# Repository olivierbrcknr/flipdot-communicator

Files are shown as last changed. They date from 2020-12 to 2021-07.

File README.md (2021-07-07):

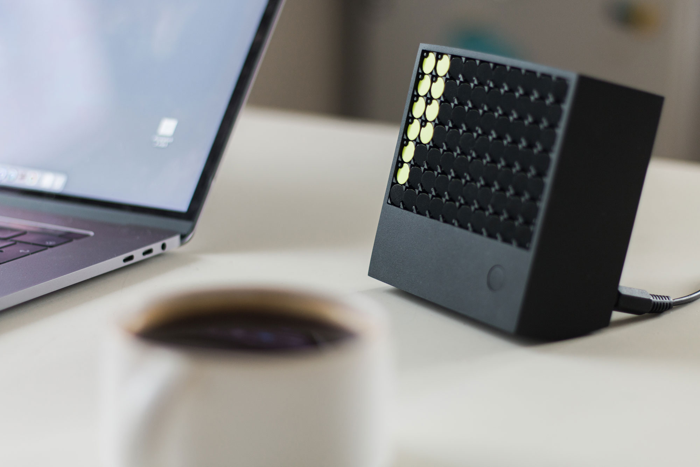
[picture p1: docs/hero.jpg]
FlipDot Communicator


# FlipDot Communicator — Distant Socializing

The *FlipDotCommunicator* is a device for ~~social distancing~~ [distant socializing](https://zirkus-zirkus.com/products/not-alone-bandana).

In these times of high paced, direct digital communication, it is a reminder of the physical and the momentariness. It is a tool to embrace non-explicit communication.

With its soft and erratic flipping sounds, it should bring a little bit of humanness back to our living space. Every message that is received is deleted immediately from the server. When pressing the button, the content is displayed. Once the button is pressed again, the transmission is gone forever. It can stay forever, but thereby it hinders new messages from being received.

It exists in this moment and this moment only—one message at a time. It forces the user to acknowledge the evanescence of a moment, pushing to cherish them more again.

###### Background

This project has been made during the class [Major Studio 1](https://courses.newschool.edu/courses/PGTE5200/1588/) by [Salome Asega](http://www.salome.zone) and [American Artist](https://americanartist.us) in the program [MFA Design & Technology](https://www.newschool.edu/parsons/mfa-design-technology) at Parsons School of Design.

Find the detailed [project blog here](https://olivierbrcknr.github.io/mfadt-ms1-blog/).

## Hardware

This project is built to use [flip-dots](https://github.com/ndsh/flipdots). The little communicator is a hardware piece that receives abstract messages. Here are some examples of how it works:

#### Read A Message
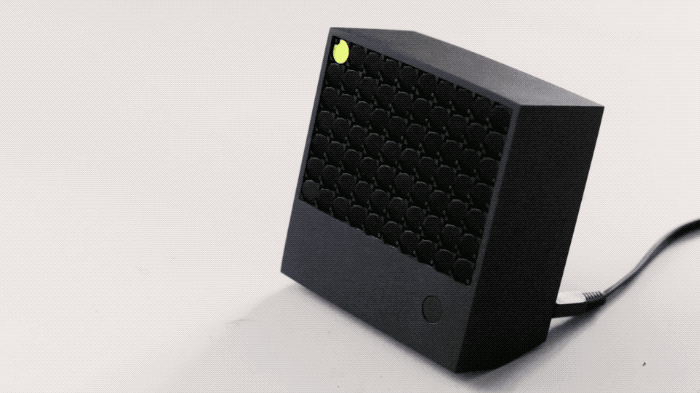
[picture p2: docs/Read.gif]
Read a message


Messages are indicated by the a flipped pixel (see top left). If a message is in the queue and the button is pressed, it is displayed.

#### Queue Is Empty
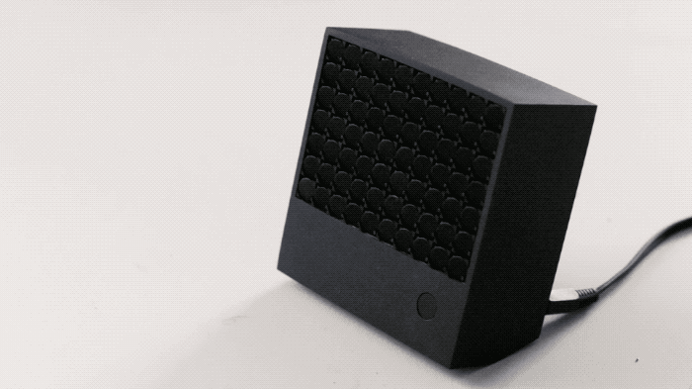
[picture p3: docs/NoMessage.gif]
No message


If no message is in the queue but the button is pressed, a sad icon is displayed for 2 seconds.

#### Timer Starts
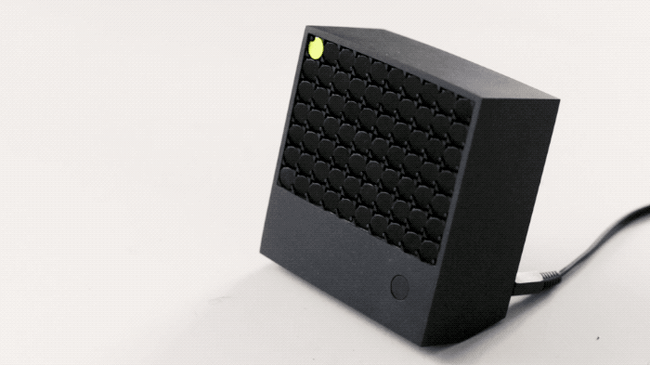
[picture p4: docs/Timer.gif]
Timer starts


If a timer is sent, the current message is saved and the timer starts to run. From start to end, the timer runs for about 3 minutes, filling the screen with dots accordingly.

## Build your own

Find the instructions to build your own hardware prototype in this file → [hardware/README.md](hardware)

## Website

To send messages, [this website](https://flipdot.vercel.app/) acts as the input device. It allows for granular messaging and will be developed further. Find more about it in this file → [website/README.md](website)

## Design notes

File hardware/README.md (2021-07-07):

# Hardware Instructions — FlipDot Communicator

## Components used

- 2 Flip Dot Displays 5✕7 from [hannIO](https://hannio.org/)
- ESP32*
- 3 [jack panel sockets](https://secure.reichelt.com/de/en/jack-panel-socket-3-5-mm-stereo-4-pin-smd-lum-1503-13v-p116190.html?&nbc=1)
- Strip board 
- Button (10✕10mm; 7mm)
- AUX cable
- AC/DC adapter 12V 5A**
- 4 M3 nuts
- 4 M3 10mm screws

*I used a [ESP32 DoIt Dev Kit](https://docs.zerynth.com/latest/reference/boards/doit_esp32/docs/). Could be they have different form factors, so check that maybe if you want to use the case I created.

**I use 5A. 1.5A seemed to work sometimes, but was not really reliable. I could not find a documentation specifying which is the minimum current needed.

### Case

Find the `.stl` files in the ["case" folder](case) to print out the housing on a 3D printer. It consists of three elements:

* [The main case](case/MainCase.stl)
* [The back cover](case/BackCover.stl)
* [A button](case/Button.stl)

### FlipDot Matrix

Here you can find the library for the flip dots along with some helpful [instructions](https://github.com/ArduinoHannover/FlipDot_5x7). Also [this video](https://www.youtube.com/watch?v=s-VXi5K4Zl0) is quite helpful to see the parts from different angles. **It's german though!**

I managed to get the two PCBs a little bit closer to each other by going without the accepting header pins and directly soldering them together. This way I could save a couple of millimeters. 

**! Watch out:** The connection to daisychain them is confusingly communicated on [the schematics from hannIO](https://github.com/ArduinoHannover/FlipDot_5x7/blob/master/5x7FlipDotController2-5_Connection_Diagram.pdf), it needs to be the other way around when looking from the back. 

### Wiring Schematics

Wiring

|ESP32|FlipDot|Button|Color Reference|
|-----|---|---|---|
|VIN  |5V |- |Orange |
|D5 |LAT |- |Green |
|GND  |GND |Pin |Gray |
|D19  |SCL |- |Yellow |
|D18  |SDA |- |Blue |
|- |GND |- |White |
|- |12V |- |Red |
|- |12V |- |- |
|D15  |- |Pin |Purple |

### Final Assembly

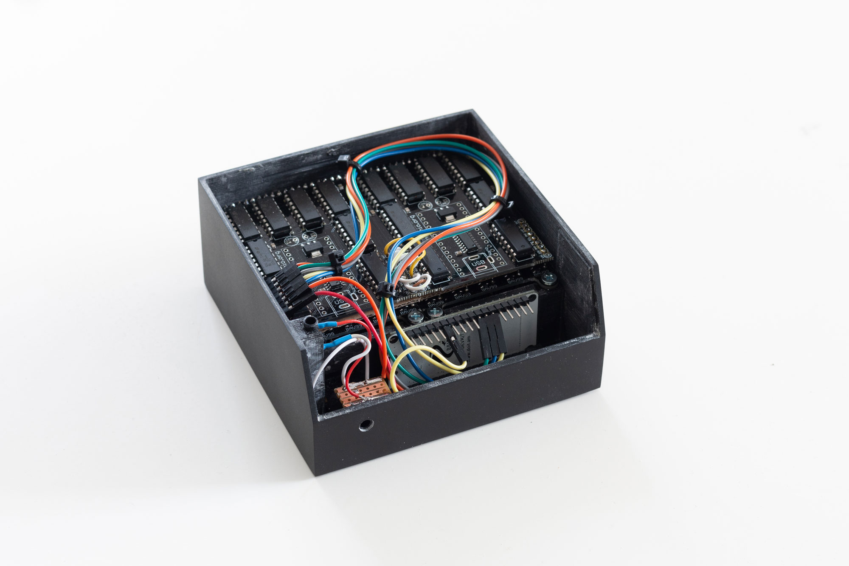
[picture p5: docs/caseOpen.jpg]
Case open


## Software

The software for the ESP32 is built using the [Arduino IDE](https://www.arduino.cc/en/software). You can find all the files here → [`FlipDotCommunicator/`](FlipDotCommunicator)

### Libraries to install

You will need to install these libraries for the code to work:

* [ESP32](https://github.com/espressif/arduino-esp32)
* [FlipDot](https://github.com/ArduinoHannover/FlipDot_5x7)
* [Firebase ESP32](https://github.com/mobizt/Firebase-ESP32)

#### Adjustments

I needed to change the pin layout in the [FlipDot_5x7.h](https://github.com/ArduinoHannover/FlipDot_5x7/blob/5966683c8d426884d215b8a05659c2891b238b62/FlipDot_5x7.h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) to this one, as it seems to need four analog pins (lines 63-76):

```cpp
#ifndef ESP8266
class FlipDot_5x7_Slave : public FlipDot_5x7 {
  private:
    const uint8_t
      addr1 = 32,
      addr2 = 33,
      addr3 = 34,
      addr4 = 35;
  public:
    FlipDot_5x7_Slave(boolean invert) : FlipDot_5x7(1,1,invert) {}
    void begin(void);
    void receiveEvent(int);
};
#endif /* ESP8266 */
```

### Flash the ESP32

Next, open the [`.ino`](hardware/FlipDotCommunicator/FlipDotCommunicator.ino) file. Add your credentials to the `credentials.h` file. The placeholders are these ones:

```cpp
#define FIREBASE_HOST "YOUR_FIREBASE_PROJECT.firebaseio.com"
#define FIREBASE_AUTH "YOUR_FIREBASE_DATABASE_SECRET"
#define WIFI_SSID "YOUR_WIFI_SSID"
#define WIFI_PASSWORD "YOUR_WIFI_PASSWORD"
```

If you are not sure where to find the Firebase credentials, this [stackoverflow question](https://stackoverflow.com/questions/37418372/firebase-where-is-my-account-secret-in-the-new-console) will help you.

Finally flash it onto the board. Now you should be all set up!

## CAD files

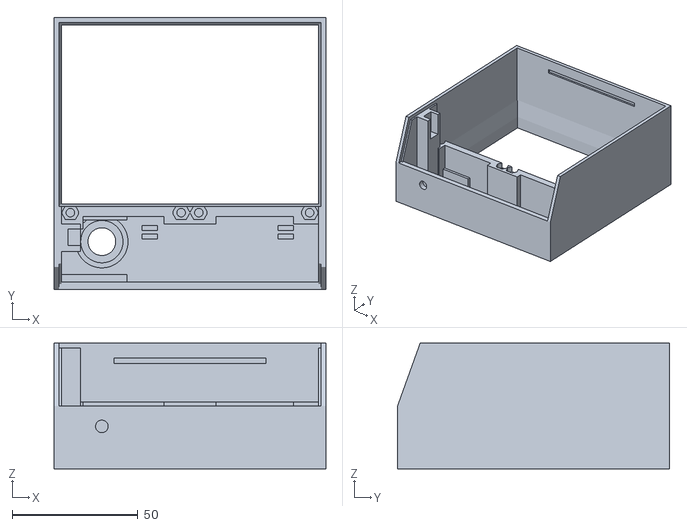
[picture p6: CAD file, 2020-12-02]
hardware/case/MainCase.stl
108.0 x 108.0 x 50.0

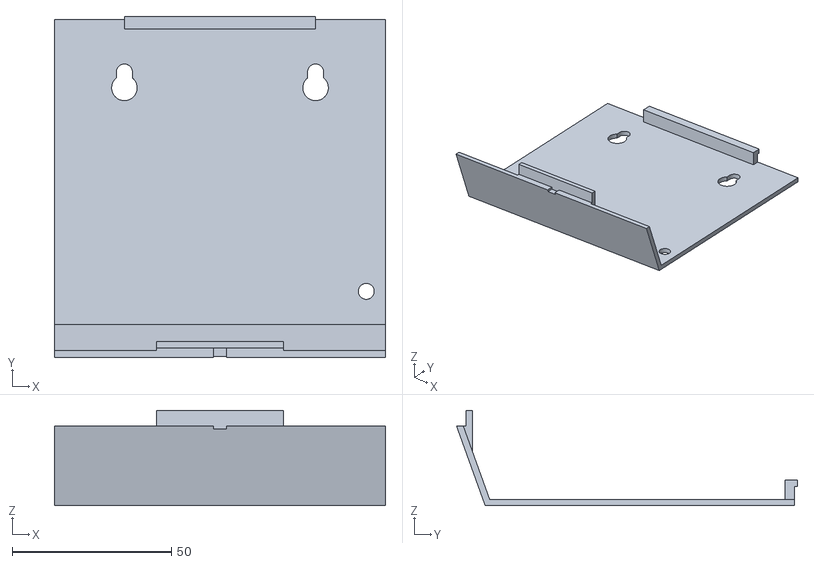
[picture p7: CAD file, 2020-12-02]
hardware/case/BackCover.stl
104.0 x 107.0 x 29.9

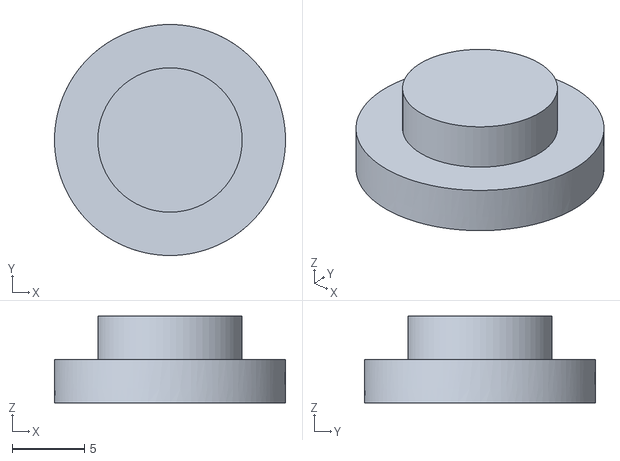
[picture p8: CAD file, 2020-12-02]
hardware/case/Button.stl
16.0 x 16.0 x 6.00

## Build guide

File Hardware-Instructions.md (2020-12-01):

# Hardware Instructions — FlipDot Communicator

## Components used

- 2 ✕ Flip Dot Displays 5✕7 from [hannIO](https://hannio.org/)
- ESP32 Dev Kit
- 2 ✕ phone jacks
- Strip board 
- Button
- AUX cable
- AC/DC adapter 12V 5A*

*I use 5A. 1.5A seemed to work, but did a lot of mistakes. I could not find a documentation specifying which is the minimum current needed.

## Assembly

### Case

Find the `.obj` file to print out the case on a 3D printer.

### FlipDot Matrix

[Instructions](https://github.com/ArduinoHannover/FlipDot_5x7)

I managed to get them a little bit closer to each other by going without the accepting header pins and directly soldering the two PCBs together. This way I could save a couple of millimeters. 

**! Watch out:** The connection to daisychain them is confusingly communicated on the schematics from hannIO, it needs to be the other way around when looking from the back. 

[Video](https://www.youtube.com/watch?v=s-VXi5K4Zl0) (german)

### Pin Layout

|ESP32|FlipDot|Button|Color (in my case)|
|-----|---|---|---|
|VIN  |5V |- |Orange |
|D5 |LAT |- |Green |
|GND  |GND |Pin |Gray |
|D19  |SCL |- |Yellow |
|D18  |SDA |- |Blue |
|- |GND |- |White |
|- |12V |- |Red |
|- |12V |- |- |
|D15  |- |Pin |Purple |

## Software

### Libraries to install

* ESP32
* FlipDot
* Firebase ESP32 

#### Adjustments

I needed to change the pin layout in the [FlipDot_5x7.h](https://github.com/ArduinoHannover/FlipDot_5x7/blob/5966683c8d426884d215b8a05659c2891b238b62/FlipDot_5x7.h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) to this one, as it seems to need four analog pins (lines 63-76):

```cpp
#ifndef ESP8266
class FlipDot_5x7_Slave : public FlipDot_5x7 {
	private:
		const uint8_t
			addr1	= 32,
			addr2	= 33,
			addr3	= 34,
			addr4	= 35;
	public:
		FlipDot_5x7_Slave(boolean invert) : FlipDot_5x7(1,1,invert) {}
		void begin(void);
		void receiveEvent(int);
};
#endif /* ESP8266 */
```

### Flash the ESP32

Then open the [`.ino`](hardware/FlipDotCommunicator/FlipDotCommunicator.ino) file. Add your credentials to the `credentials.h` file. The placeholders are these ones:

```cpp
#define FIREBASE_HOST "YOUR_FIREBASE_PROJECT.firebaseio.com"
#define FIREBASE_AUTH "YOUR_FIREBASE_DATABASE_SECRET"
#define WIFI_SSID "YOUR_WIFI_AP"
#define WIFI_PASSWORD "YOUR_WIFI_PASSWORD"
```

If you are not sure where to find them, this [stackoverflow question](https://stackoverflow.com/questions/37418372/firebase-where-is-my-account-secret-in-the-new-console) will help you.

Finally flash it onto the board.

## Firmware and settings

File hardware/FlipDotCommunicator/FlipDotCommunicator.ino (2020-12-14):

#include "credentials.h"
#include "icons.h"

#include <FlipDot_5x7.h>
#include <WiFi.h>
#include <FirebaseESP32.h>

#define CLOCK 19
#define DATA  18
#define LATCH 5

#define BTN   15

int buttonIsPressed = false;

FlipDot_5x7 flipdot(2, 1, false);

int COLUMNS = 10;
int ROWS = 7;

FirebaseData firebaseData;
FirebaseJsonData jsonData;
FirebaseJson json;
FirebaseJsonArray arr;
void printResult(FirebaseData &data);

unsigned long sendDataPrevMillis = 0;
uint16_t count = 0;

int checkTime = 5000; // in ms

String path = "/flipMessages/physical";

String currentType = "";
String currentContent = "";
String currentKey = "";

int prevMessageCount = 0;
int totalMessageCount = 0;

// give space for 70 pixels in matrix
int matrix[70];

bool isAnimating = false;
bool isDisplayingMessage = false;
char refChar = '1';

bool isTimer = false;
int timerCount = 0;
int timerTotalTime = 3 * 60 * 1000;
int timerIncrementTime = timerTotalTime / (COLUMNS*ROWS);
int lastTimerIncrementTime = 0;

void resetMatrix( bool shouldDisplay = true );

void setup() {

  Serial.begin(115200);

  // init Button
  pinMode(BTN, INPUT_PULLUP);
  
  // init WiFi
  WiFi.begin(WIFI_SSID, WIFI_PASSWORD);
  Serial.print("Connecting to Wi-Fi");
  while (WiFi.status() != WL_CONNECTED)
  {
    Serial.print(".");
    delay(300);
  }
  Serial.println();
  Serial.print("Connected with IP: ");
  Serial.println(WiFi.localIP());
  Serial.println();

  // init Firebase
  Firebase.begin(FIREBASE_HOST, FIREBASE_AUTH);
  Firebase.reconnectWiFi(true);
  
  Firebase.setReadTimeout(firebaseData, 1000 * 60);
  Firebase.setwriteSizeLimit(firebaseData, "small");
  firebaseData.setResponseSize(12288);

  Firebase.setFloatDigits(2);
  Firebase.setDoubleDigits(6);


  if (!Firebase.beginStream(firebaseData, path))
  {
      Serial.println("------------------------------------");
      Serial.println("Can't begin stream connection...");
      Serial.println("REASON: " + firebaseData.errorReason());
      Serial.println("------------------------------------");
      Serial.println();
  }
  

  // init flipdot and flip all of them briefly
  flipdot.begin(DATA, CLOCK, LATCH);
  flipdot.fillScreen(FLIPDOT_YELLOW);
  flipdot.display();
  delay(1000);
  flipdot.fillScreen(FLIPDOT_BLACK);
  flipdot.display();
  delay(1000);
}

void loop() {

  bool buttonEventHasHappened = false;
  buttonIsPressed = digitalRead(BTN) ? false : true;

  if (millis() - sendDataPrevMillis > checkTime && !isTimer){
    sendDataPrevMillis = millis();
    count++;
    prevMessageCount = totalMessageCount;
    checkForMessages();
  }
  
  // only update queue if is new
  if( prevMessageCount != totalMessageCount && !isDisplayingMessage ){
    prevMessageCount = totalMessageCount;
    displayQueue();
    delay(500);
  }

  // prevent button listener when animating

  if( buttonIsPressed && !isDisplayingMessage && !isAnimating && !buttonEventHasHappened && !isTimer && totalMessageCount > 0 ){
    buttonEventHasHappened = true;
    Serial.print("Displaying Message: ");
    Serial.println( currentType );
    
    isAnimating = true;
    isDisplayingMessage = true;
    
    resetMatrix();
    deleteCurrentMessage();
    
    switch ( currentType.charAt(0) ){
      case 'h':
        sweepAnimation();
        isDisplayingMessage = false;
        resetMatrix();
        displayQueue();
        
        break;
    
      case 'm':
        // star animation
        starAnimation();
        isDisplayingMessage = false;
        displayQueue();
        
        break;
      case 'a':
      
        // display the sent array  
        char pixelChars[70];
        currentContent.toCharArray(pixelChars, 70);
        for( int i = 0; i < COLUMNS * ROWS; i++ ){
          bool pixel = false;
          if( pixelChars[i] == refChar ){
            pixel = true;
          }          
          matrix[i] = pixel;
        }    
        displayMatrix();
        delay(500);
        
        break;
      default:

        Serial.println("Sorry, does not exist yet");
        break;
    }
    isAnimating = false;
  }

  // if is message
  if( buttonIsPressed && isDisplayingMessage && !isAnimating && !buttonEventHasHappened && !isTimer ){
    buttonEventHasHappened = true;
    Serial.println("Displaying queue again");
    isDisplayingMessage = false;
    isAnimating = true;
    resetMatrix();
    displayQueue();
    delay(500);
    isAnimating = false;
  }

  if( isTimer ){
    displayTimer();  
  }

  // if is timer
  if( buttonIsPressed && !buttonEventHasHappened && isTimer ){
    buttonEventHasHappened = true;
    Serial.println("Displaying prev state again");
    isTimer = false;
    timerCount = 0;
    delay(500);
    if( !isDisplayingMessage ){
      displayQueue();
    }
  }


  // display sorry no message
  if( buttonIsPressed && !buttonEventHasHappened && !isTimer && !isDisplayingMessage && !isAnimating && totalMessageCount == 0 ){
    buttonEventHasHappened = true;
    Serial.println("Sorry, no message");
    sorryNoMessage();
  }

}

void checkForMessages() {
  Serial.println("------------------------------------");
  Serial.println("Get Data...");
  totalMessageCount = 0;
  if (Firebase.get(firebaseData,  path))
  {   
    
    Serial.println("------------------------------------");
    Serial.println();

    if( firebaseData.dataType() == "json" ){

      FirebaseJson &json = firebaseData.jsonObject();
      /*
      Serial.println("Pretty printed JSON data:");
      String jsonStr;
      json.toString(jsonStr, true);
      Serial.println(jsonStr);
      Serial.println(); 
      */
      
      size_t len = json.iteratorBegin();
      String key, value = "";
      int type = 0;
      bool isNewMessage = false;

      String lastKey = "";
      
      for (size_t i = 0; i < len; i++)
      {
        json.iteratorGet(i, type, key, value);

        // save latest key to variable to remember what to play
        if( i == 0 ){
          currentKey = key;
        }

        // if is not the first element and a main key, do this
        if( i > 0 && isNewMessage == false ){

          // check what type the message is
          if(key.indexOf("type") >= 0 ){
            // Serial.println(value);
            currentType = value;
          }

          // check what content the message has
          if(key.indexOf("content") >= 0 ){
            // Serial.println(value);
            currentContent = value;
          }

          // check if new message starts
          if(value.indexOf("{") >= 0){
            // Serial.println("Contains a {}");
            isNewMessage = true;
          }
        }

        if( i > 0 ){
          if(key.indexOf("type") >= 0 ){
            if( value == "timer"){
              totalMessageCount--;
              isTimer = true;
              Serial.println("Start Timer");
              // delete message of timer as it is not needed anymore
              Firebase.deleteNode(firebaseData, path + "/" + lastKey);
            }
          }
        }
        
        // count messages
        if(value.indexOf("{") >= 0){
          totalMessageCount++;
          lastKey = key;
        }
      }
      json.iteratorEnd();

      /*
      Serial.println("Next Message —————————————— ");
      Serial.println(currentKey);
      Serial.println(currentType);
      Serial.println(currentContent);
      Serial.println();
      */

      Serial.print("Total Messages: ");
      Serial.println(totalMessageCount);        
    }
  } else {
    Serial.println("FAILED");
    Serial.println("REASON: " + firebaseData.errorReason());
    Serial.println("------------------------------------");
    Serial.println();
  }
}

void deleteCurrentMessage() {
  // remove one count just in case
  totalMessageCount--;
  Firebase.deleteNode(firebaseData, path + "/" + currentKey);
}

void displayTimer() {
  if (millis() - lastTimerIncrementTime > timerIncrementTime){
    lastTimerIncrementTime = millis();
    timerCount++;
  

    for ( int y = 0; y < ROWS; y++ ){
      for( int x = 0; x < COLUMNS; x++ ){
        int i = x + y*COLUMNS;
        int k = y + x*ROWS;
        bool colorPixel = ( k < timerCount ) ? true : false;
        flipdot.drawPixel(x, y, ( colorPixel ? FLIPDOT_YELLOW : FLIPDOT_BLACK ) );
      }
    }
    flipdot.display();
    
    if( timerCount >= ROWS * COLUMNS ){
      isTimer = false;
      timerCount = 0;

      if( !isDisplayingMessage ){
        displayQueue();
      }
    }
  }
}

void displayQueue() {
  for ( int y = 0; y < ROWS; y++ ){
    for( int x = 0; x < COLUMNS; x++ ){
      int i = x + y*COLUMNS;
      int k = y + x*ROWS;
      bool colorPixel = ( k < totalMessageCount ) ? true : false;
      flipdot.drawPixel(x, y, ( colorPixel ? FLIPDOT_YELLOW : FLIPDOT_BLACK ) );
    }
  }
  flipdot.display();
}

void displayMatrix() {
  for ( int y = 0; y < ROWS; y++ ){
    for( int x = 0; x < COLUMNS; x++ ){
      int i = x + y*COLUMNS;
      
      bool colorPixel = matrix[i] ? true : false;

      flipdot.drawPixel(x, y, ( colorPixel ? FLIPDOT_YELLOW : FLIPDOT_BLACK ) );
    }
  }
  flipdot.display();
}

void resetMatrix( bool shouldDisplay ) {
  for( int i = 0; i < ROWS*COLUMNS; i++ ){
    matrix[i] = 0;
  }
  if( shouldDisplay ){
    flipdot.fillScreen(FLIPDOT_BLACK);
    flipdot.display();
  }
}

void sorryNoMessage(){
  for( int i = 0; i < COLUMNS * ROWS; i++ ){
    matrix[i] = ICON_SAD[i];  
  }    
  displayMatrix();
  delay(2000);
  resetMatrix();
}

void sweepAnimation() {
  int printedColumns = 0;
  for ( int x = 0; x < COLUMNS; x++ ){
    resetMatrix( false );
    for (int y = 0; y < ROWS; y++) {
      matrix[y*COLUMNS+printedColumns] = true;
    }
    displayMatrix();
    delay(100);
    printedColumns++;
  }
  delay(100);
  resetMatrix();
  delay(500);
}

void starAnimation(){

  int StarAnimDelay = 130;

  for( int i = 0; i < COLUMNS * ROWS; i++ ){
    matrix[i] = ANIM_STAR_1[i];  
  }    
  displayMatrix();
  delay(StarAnimDelay);
  for( int i = 0; i < COLUMNS * ROWS; i++ ){
    matrix[i] = ANIM_STAR_2[i];  
  }    
  displayMatrix();
  delay(StarAnimDelay);
  for( int i = 0; i < COLUMNS * ROWS; i++ ){
    matrix[i] = ANIM_STAR_3[i];  
  }    
  displayMatrix();
  delay(StarAnimDelay);
  for( int i = 0; i < COLUMNS * ROWS; i++ ){
    matrix[i] = ANIM_STAR_4[i];  
  }    
  displayMatrix();
  delay(StarAnimDelay);
  for( int i = 0; i < COLUMNS * ROWS; i++ ){
    matrix[i] = ANIM_STAR_5[i];  
  }    
  displayMatrix();
  delay(StarAnimDelay);
  resetMatrix();
  delay(500);
 
}

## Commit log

2020-11-30 Add basic hardware instructions for ESP32
2020-12-01 Refactor arduino code to prevent flipdots from overheating
    [FlipDotCommunicator.ino]
2020-12-02 Add STL files for case
    [BackCover.stl, Button.stl, MainCase.stl]
2020-12-10 Add Timer
    - Add "no message" icon
    - Fix buffer issue (max 82 messages)
    - Add prevention if more than 70 physical messages
    - Add timer
    [FlipDotCommunicator.ino]
2020-12-14 Match interactions
    - Fix interaction on virtual
    - Fix bug on type selection
    - Fix timer issue on website
    - Add star animation to hardware (basic)
    [FlipDotCommunicator.ino]
